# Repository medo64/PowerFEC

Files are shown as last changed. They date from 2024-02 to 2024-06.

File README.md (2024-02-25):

Power Framework Expansion Card
==============================

Non-isolated 5V output with a 500 mA current limit.

## Pinout

To connect to this board, one has to use a 2-pin JST XH connector. The following
table represents the pinout, pin 1 being on the left as looking into the
expansion card.

| # | Ref | Description |
|--:|:-----:|---|
| 1 | GND | Ground connection |
| 2 | 5V | Positive voltage |

## LEDs

Left LED signals if input is powered. It is expected to be on at all times.

Right LED signals if output is powered and there are no faults. It will turn off
if there is an over-current state (typically at around `525 mA`).

## Commands

Each char is a separate command. If it is recognized, output will be tilde
character (`~`), original command, and `CR``LF`.

| Char | Description |
|---|---|
| `0`  | No smoothing for voltage and current |
| `1`  | Voltage and current read are smoothed over 2 readings |
| `2`  | Voltage and current read are smoothed over 4 readings |
| `3`  | Voltage and current read are smoothed over 8 readings |
| `4`  | Voltage and current read are smoothed over 16 readings |
| `5`  | Voltage and current read are smoothed over 32 readings |
| `6`  | Voltage and current read are smoothed over 64 readings |
| `7`  | Voltage and current read are smoothed over 128 readings |
| `8`  | Voltage and current read are smoothed over 256 readings |
| `9`  | Voltage and current read are smoothed over 512 readings |
| `d`  | Disable output |
| `D`  | Disable output and allow saving for startup |
| `e`  | Enable output |
| `E`  | Enable output and allow saving for startup |
| `S`  | Saves current settings |

Any command state that can be saved permanently (e.g. `E`) needs to be followed
by `S` command in order to be saved.

---
*You can check my blog and other projects at [www.medo64.com](https://www.medo64.com/electronics/).*

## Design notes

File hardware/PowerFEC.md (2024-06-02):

### PowerFEC Parts

|  # | Part | RefDes  | Preferred Part Number |
|---:|---|---|---|
|  1 | C 10nF X7R 16V (0805) † | C1 | 399-17617-1-ND |
|  3 | C 100nF X7R 16V (0805) | C2-C4 | 478-5311-1-ND |
|  1 | C 100nF X7R 16V (0805) † | C5 | 478-5311-1-ND |
|  1 | C 1uF 16V X7R (0805) | C6 | 1276-6470-1-ND |
|  2 | C 10uF X5R 16V (0805) | C7-C8 | 1276-1096-1-ND |
|  2 | DS LED (0805) | DS1-DS2 | 475-1415-1-ND |
|  1 | P USB C, plug, straddle 0.8mm | J1 | WM12855-ND |
|  1 | J JST XH Vertical (2w) | J2 | 455-B2B-XH-A-ND |
|  1 | L Ferrite 600R@100Mhz | L1 | 240-2390-1-ND |
|  1 | R 0.1, 0.5%, 0.5W (1206) | R1 | 273-KDV12DR100ETCT-ND |
|  4 | R 1K 0.125W (0805) | R2-R5 | RMCF0805FT1K00CT-ND |
|  2 | R 5.1K 0.125W (0805) | R6-R7 | RMCF0805FT5K10CT-ND |
|  2 | R 5.1K 0.125W (0805) † | R8-R9 | RMCF0805FT5K10CT-ND |
|  1 | R 56K 0.125W (0805) | R10 | RMCF0805FT56K0CT-ND |
|  1 | U PIC16F1455 (SOIC-14) | U1 | PIC16F1455-I/SL-ND |
|  1 | U AP22652 | U2 | 31-AP22652AW6-7CT-ND |
|  1 | U ZXCT1009 (SOT23) | U3 | ZXCT1109QSA-7DICT-ND |
|  1 | U MCP3422 (SOIC-8) † | U4 | MCP3422A1T-E/SNCT-ND |
|  2 | H Screw M2x3mm | - | - |

† optional 18-bit ADC

#### Board Size

| | Dimensions | Area | Thickness |
|---|---|---|---|
| PCB |  24.0 x 27.9 mm | 1.1 in² | 0.8 mm |

#### ADC

ADC uses internally available PIC `1.024 V` voltage reference and all
measurements are done in `10 bits` (optionally, at 18-bit resolution).

Since current sense resistor is `100 mΩ`, having `1 kΩ` resistor on Iout gives
us nice 1:1 V/A ratio. Resolution is about `0.98 mA` per bit (at 18-bit,
`3.8 uA` per bit with 2x gain).

Voltage measurement for output uses `5.1 kΩ` and `1 kΩ` voltage divider thus
having 6.1:1 ratio. Resolution is about `6 mV` per bit (at 18-bit, `23.3 uV` per
bit with 2x gain).

#### Specification

| | Minimum | Typical | Maximum |
|---|---:|---:|---:|
| Input voltage:  | | 5.0 V | |
| Input current:  | |  560 mA | |
| Output voltage: |  4.75 V | 5.0 V |  545 mA |
| Output current: |  490 mA |  525 mA |  545 mA |

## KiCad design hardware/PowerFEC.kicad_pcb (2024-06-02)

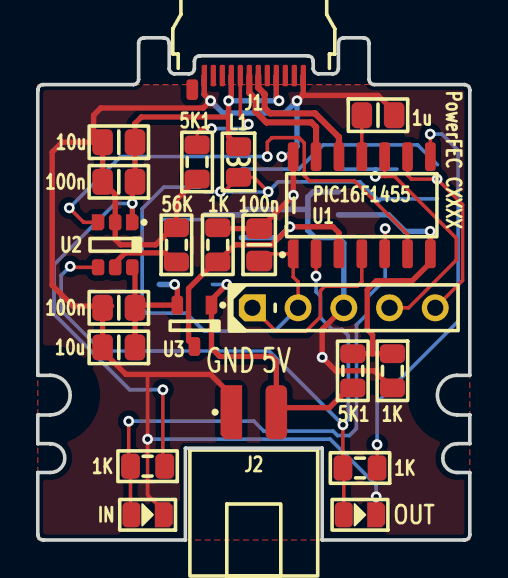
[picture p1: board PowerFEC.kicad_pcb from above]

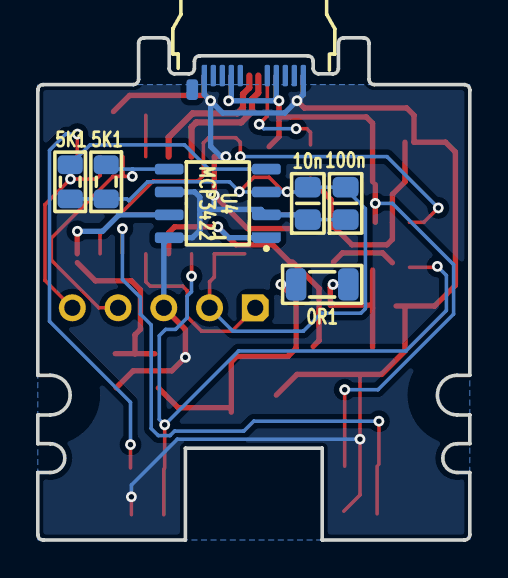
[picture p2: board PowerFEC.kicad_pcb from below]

Board: 2 copper layers, 24.0 x 27.9 mm, 28 parts (6 on the bottom side), 19 nets.

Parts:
C1: 10n; C (0805)
C2, C3, C4, C5: 100n; C (0805)
C6: 1u; C (0805)
C7, C8: 10u; C (0805)
DS1: IN; DS (0805)
DS2: OUT; DS (0805)
ICSP: Microchip PIC; ICSP PIC Pogo (5w)
J1: 105444-0001; J USB C 3.2 Edge (24w)
J2: B2B-XH-A; J JST XH Edge [POWER] (2w)
L1: 1u; L (0805)
R1: 0R1; R (1206)
R2, R3, R4, R5: 1K; R (0805)
R6, R7, R8, R9: 5K1; R (0805)
R10: 56K; R (0805)
U1: PIC16F1455; U Micro [PIC16F1455] (SOIC-14)
U2: AP22652; U LoadSwitch Adjustable [AP22652AW6-7] (SOT23-6)
U3: ZXCT1009; U Current Monitor [ZXCT1009] (SOT23-3)
U4: MCP3422; U ADC 18bit 2ch [MCP3422] (SOIC-8)

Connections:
5V: C1.1, C4.1, C5.1, ICSP.2, L1.2, R8.1, R9.1, U1.1, U4.3
A_CC: J1.A5, R6.2
GND: C1.2, C2.2, C3.2, C4.2, C5.2, C6.2, C7.2, C8.2, DS1.1, DS2.1, ICSP.3, J1.A1, J1.A12, J1.B01, J1.B12, J2.1, R2.2, R5.2, R6.1, R10.2, U1.14, U2.2, U4.2, U4.6, U4.8
ICSP_CLK/SDA: ICSP.5, R9.2, U1.9, U4.4
ICSP_DAT/SCL: ICSP.4, R8.2, U1.10, U4.5
ICSP_VPP: ICSP.1, U1.4
ILIM: R10.1, U2.5
Iadc: R2.1, U1.3, U3.3, U4.1
LED_IN: DS1.2, R3.2, U1.5
LED_OUT_HIGH: R4.1, U1.8
POWER_EN: U1.6, U2.3
POWER_FAULT: DS2.2, R4.2, U1.2, U2.4
USB_DM: J1.A7, U1.12
USB_DP: J1.A6, U1.13
V33: C6.1, U1.11
Vadc: R5.1, R7.2, U1.7, U4.7
Vin: C2.1, C7.1, J1.A4, J1.A9, J1.B04, J1.B09, L1.1, R3.1, U2.1
Vout: J2.2, R1.2, R7.1, U3.1
Vsw: C3.1, C8.1, R1.1, U2.6, U3.2

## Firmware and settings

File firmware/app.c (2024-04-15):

#include <xc.h>
#include <stdint.h>
#include "app.h"
#include "appUsb.h"
#include "adc.h"
#include "io.h"
#include "settings.h"
#include "ticker.h"
#include "watchdog.h"

void init(void) {
    interruptsDisable();

    // Oscillator
    OSCCONbits.IRCF = 0b1111;  // 16 MHz or 48 MHz HF
    OSCCONbits.SPLLMULT = 1;   // 3x PLL is enabled
    OSCCONbits.SPLLEN = 1;     // PLL is enabled
    ACTCONbits.ACTSRC = 1;     // The HFINTOSC oscillator is tuned using Fll-speed USB events
    ACTCONbits.ACTEN = 1;      // ACT is enabled, updates to OSCTUNE are exclusive to the ACT
}

void main(void) {
    init();
    io_init();
    adc_init();
    ticker_init();
    settings_init();
    watchdog_init();


    for (uint8_t i = 0; i < 3; i++) {
        out_led1_on(); out_led2_off(); ticker_waitTicks(3);
        out_led1_off(); out_led2_on(); ticker_waitTicks(3);
    }
    out_led2_off();


    // ADC offset
    if (settings_getZeroCurrentAdc() == 0xFF) {  // first time after programming set offset
        watchdog_clear();
        uint16_t value = adc_getRawCurrent();
        if (value < 0xFF) {
            settings_setZeroCurrentAdc((uint8_t)value);
            settings_save();
        }

        while (true) {
            watchdog_clear();
            out_led1_on();  out_led1_on();  ticker_waitTicks(3);
            out_led1_off(); out_led2_off(); ticker_waitTicks(3);
        }
    }
    adc_setCurrentOffset(settings_getZeroCurrentAdc());


    watchdog_clear();
    execUsb();
}

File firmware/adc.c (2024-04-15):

#include <xc.h>
#include <stdbool.h>
#include "adc.h"
#include "Microchip/usb_device.h"

#define ADC_VOLTAGE_BIT_MULTIPLIER  6034  // should be 6100
#define ADC_CURRENT_BIT_MULTIPLIER   978  // should be 1000

void adc_init(void) {
    FVRCONbits.ADFVR = 0b01;     // ADC Fixed Voltage Reference Peripheral output is 1x (1.024V)
    FVRCONbits.FVREN = 1;        // Fixed Voltage Reference is enabled
    while (!FVRCONbits.FVRRDY);  // Fixed Voltage Reference output is ready for use

    ADCON1bits.ADFM = 1;         // right justified
    ADCON1bits.ADCS = 0b111;     // dedicated RC oscillator
    ADCON1bits.ADPREF = 0b11;    // VREF+ is connected to FVR

    ADCON0bits.CHS = 0b111;      // select FVR
    ADCON0bits.ADON = 1;         // ADC is enabled
}

uint16_t adc_getRaw(uint8_t channel) {
    ADCON0bits.CHS = 0b111;       // select FVR
    ADCON0bits.GO_nDONE = 1;      // start an A/D conversion cycle
    while (ADCON0bits.GO_nDONE);  // wait for conversion to complete

    ADCON0bits.CHS = channel;     // select channel
    ADCON0bits.GO_nDONE = 1;      // start an A/D conversion cycle
    while (ADCON0bits.GO_nDONE);  // wait for conversion to complete
    uint16_t value1 = ADRES;

    ADCON0bits.GO_nDONE = 1;      // start an A/D conversion cycle
    while (ADCON0bits.GO_nDONE);  // wait for conversion to complete
    uint16_t value2 = ADRES;

    ADCON0bits.CHS = 0b111;       // select FVR

    uint16_t result = (value1 + value2 + 1) / 2;
    return result;
}

uint16_t adc_getVoltage() {
    uint32_t value = adc_getRaw(7);
    value *= ADC_VOLTAGE_BIT_MULTIPLIER;
    value /= 1000;
    return (uint16_t)value;
}

uint16_t adc_getRawCurrent() {
    return adc_getRaw(3);
}

uint8_t offsetCurrent;
void adc_setCurrentOffset(uint8_t offset) {
    offsetCurrent = offset;
}

uint16_t adc_getCurrent() {
    uint32_t value = adc_getRawCurrent();
    if (value <= offsetCurrent) { value = 0; } else { value -= offsetCurrent; }
    value *= ADC_CURRENT_BIT_MULTIPLIER;
    value /= 1000;
    return (uint16_t)value;
}

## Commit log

2023-12-30 Refactored to allow usage of PIC
    [PowerFEC.kicad_pcb]
2023-12-30 Refactoring copper pours
    [PowerFEC.kicad_pcb]
2023-12-30 Minor trace movements
    [PowerFEC.kicad_pcb]
2023-12-30 Added soldermask expand
    [PowerFEC.kicad_pcb]
2024-01-31 Moved LEDs
    [PowerFEC.kicad_pcb]
2024-02-04 Fixed current sense IC part number
2024-02-15 Moved hardware directory
    [PowerFEC.kicad_pcb]
2024-02-15 Added POWER_EN line
    [PowerFEC.kicad_pcb]
2024-02-15 Moved LED pin to allow for FAULT check (later)
    [PowerFEC.kicad_pcb]
2024-02-15 Added fault check pin
    [PowerFEC.kicad_pcb]
2024-02-17 Added option to control out LED by PIC (in addition to FAULT)
    [PowerFEC.kicad_pcb]
2024-02-17 Adjusting LEDs a bit
2024-02-17 Added control of the right LED
2024-02-19 Updated USB edge connector designator
    [PowerFEC.kicad_pcb]
2024-02-24 Renaming connectors
    [PowerFEC.kicad_pcb]
2024-04-11 Added optional 18-bit ADC support
    [PowerFEC.kicad_pcb]
2024-04-11 Changed ADC to MCP3422
    [PowerFEC.kicad_pcb]
2024-04-11 Added 10nF capacitor
    [PowerFEC.kicad_pcb]
2024-04-11 Replaced current sense resistor with smaller one
    [PowerFEC.kicad_pcb]
2024-04-15 Don't mark disabled device as faulted
2024-04-15 Fixed LED definitions (board B)
2024-04-15 Adjusted LED blinking on startup
2024-04-15 Auto-calibrate zero-offset for current
2024-04-15 Adjusted current factor a bit
2024-04-18 Added output labels
    [PowerFEC.kicad_pcb]
2024-04-18 Refactoring a bit
    [PowerFEC.kicad_pcb]
2024-04-28 Upgraded to KiCAD 8
    [PowerFEC.kicad_pcb]
2024-05-11 Updated connector
    [PowerFEC.kicad_pcb]
2024-06-02 Fixed refdes
    [PowerFEC.kicad_pcb]
